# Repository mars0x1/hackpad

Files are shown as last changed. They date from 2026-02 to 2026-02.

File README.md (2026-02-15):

# Mars Hackpad 🚀
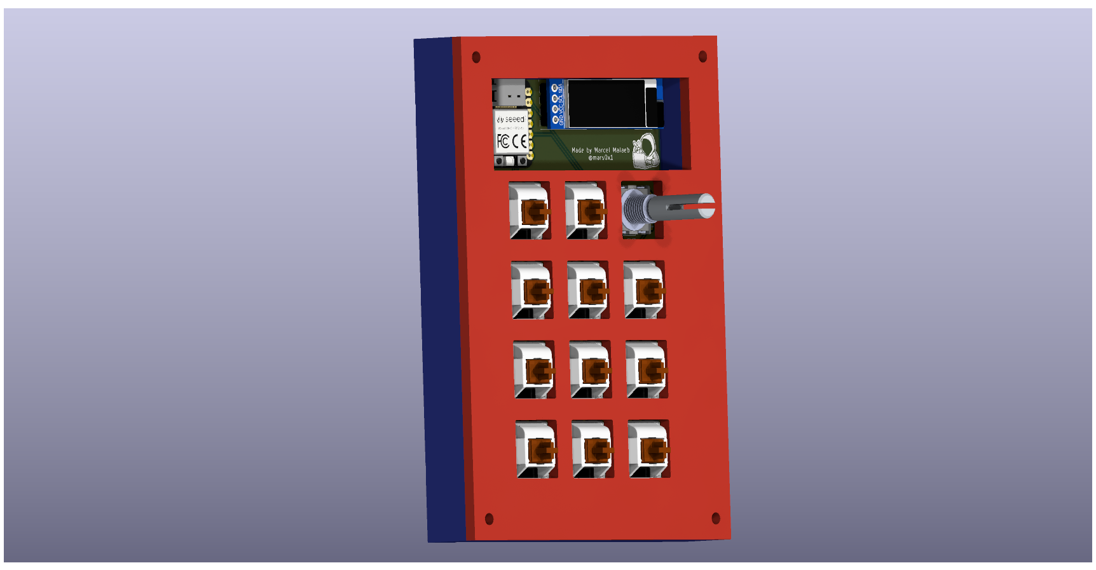
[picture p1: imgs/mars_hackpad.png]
mars_hackpad


Mars Hackpad is a 12-input productivity tool designed for seamless media control and custom shortcuts. It features an 11-key matrix and a rotary encoder, providing a tactical way to manage your workspace. It is powered by the **Seeed XIAO RP2040** and runs on **KMK firmware**.

## Features
* **128x64 OLED Display**: Provides real-time status updates via I2C (SDA: D4, SCL: D5).
* **EC11 Rotary Encoder**: Mapped to system volume control. Press the encoder to toggle **System Mute**.
* **11 Mechanical Keys**: Currently configured with macros for **Undo**, **Copy**, **Paste**, and a dedicated **Mic Mute** shortcut (FN + F5).
* **3D Printed Case**: A two-piece snap-fit design that holds the PCB and display at an ergonomic angle.

## CAD Model

* The case was designed in Fusion360 . 
* It consists of two printed parts: a **Top Case** with cutouts for the keys and screen, and a **Bottom Case** to protect the electronics.
* Everything is held together by M3 bolts.

## PCB
My PCB was designed in KiCad. It features a 4x3 matrix layout and custom silkscreen labeling.
* **Schematic**:
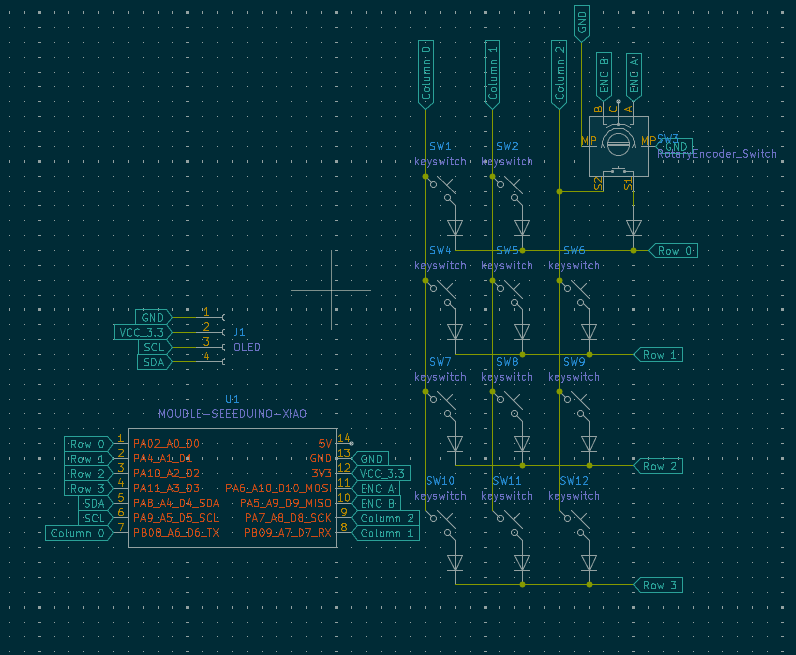
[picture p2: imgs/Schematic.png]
*  

* **PCB Layout**:
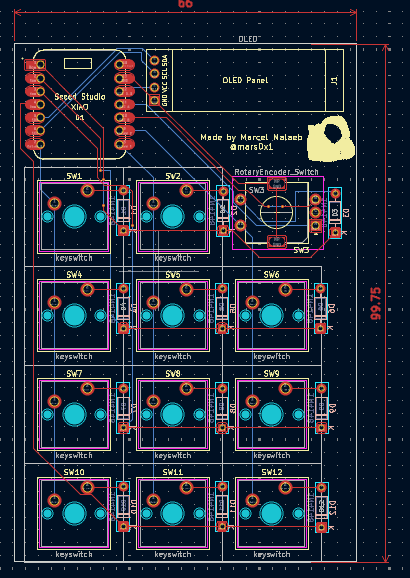
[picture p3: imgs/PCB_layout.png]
* 

* I used standard MX-style footprints for the keys and ensured the XIAO RP2040 sits centrally for easy USB-C access.
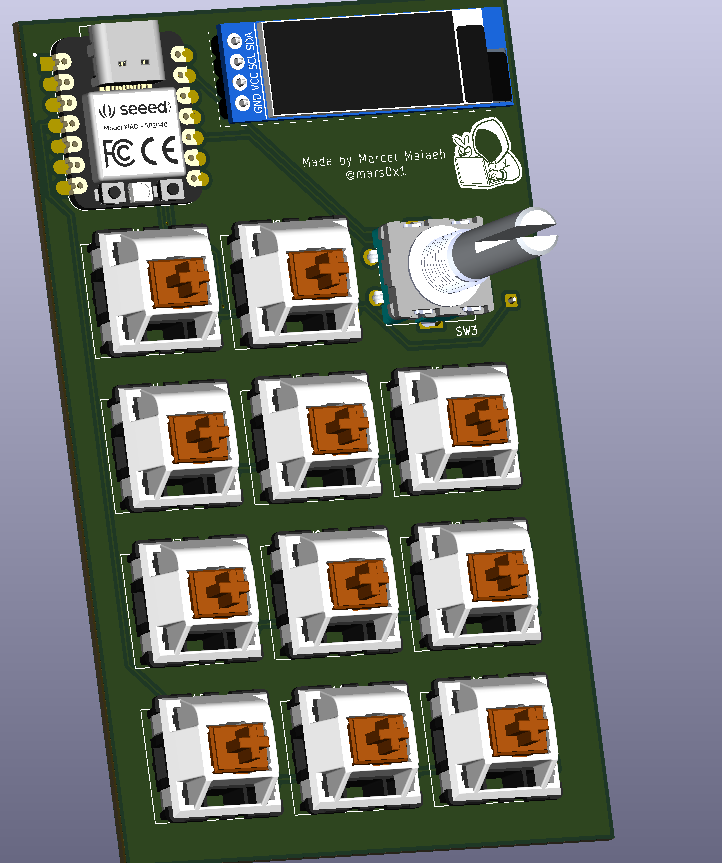
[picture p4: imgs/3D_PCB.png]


## Firmware Overview
This hackpad uses **KMK Firmware** (CircuitPython).
* **Matrix Setup**: Rows use pins **D0, D1, D2, D3** and Columns use **D6, D7, D9**.
* **Rotary Encoder**: Mapped to pins **D11** and **D10**.
* **Shortcuts**: The firmware is set up to handle common productivity commands without needing to touch the main keyboard.

## BOM (Bill of Materials)
Here is everything you need to build the Mars Hackpad:

| Item | Quantity | Description |
| :--- | :--- | :--- |
| **Seeed XIAO RP2040** | 1 | Main Microcontroller |
| **0.91 inch OLED display** | 1 | I2C Display |
| **EC11 Encoder** | 1 | Rotary Encoder with push-button |
| **MX Switches** | 11 | Your choice of mechanical switches |
| **1N4148 Diodes** | 12 | Switching Diodes for the matrix |
| **Case** | 2 parts | 3D Printed Top and Bottom shells |
| **M3 Bolts** | 4 | To secure the case halves |

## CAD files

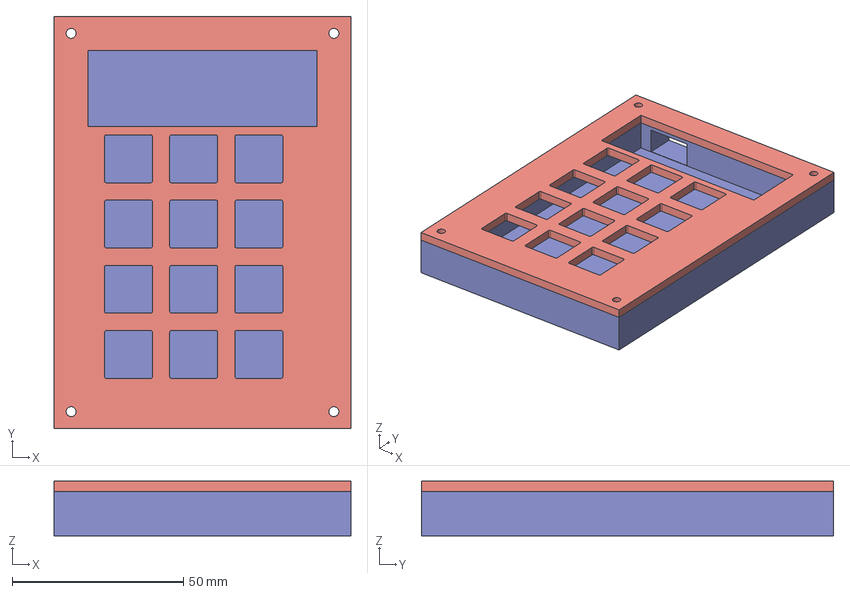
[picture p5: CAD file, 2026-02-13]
CAD/assembled_pad.step
86.8 x 120.5 x 16.0 mm

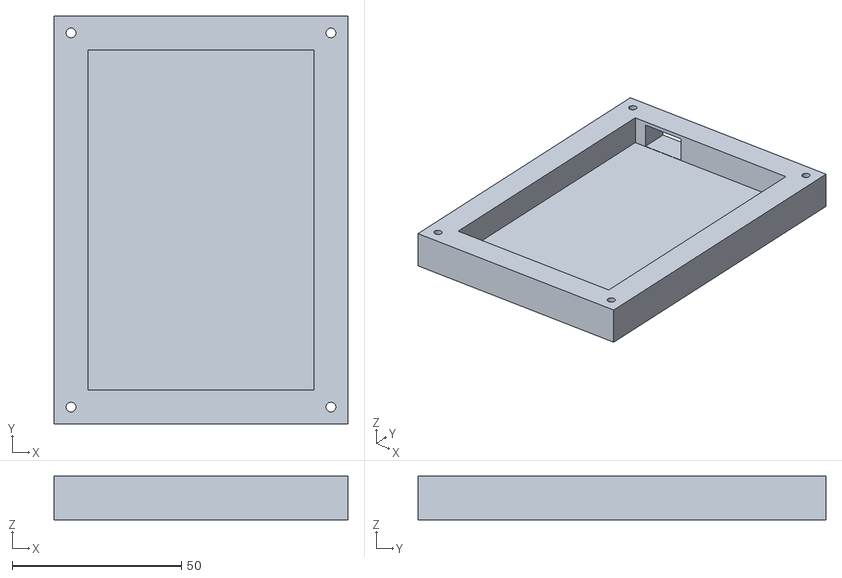
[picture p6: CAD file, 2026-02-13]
production/Bottom.stl
86.8 x 120.5 x 13.0

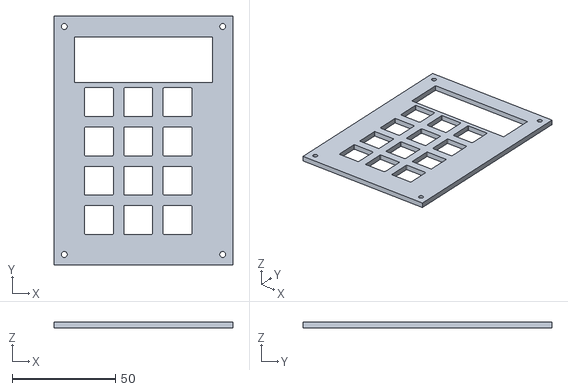
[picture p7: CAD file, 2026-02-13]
production/top.stl
86.8 x 120.5 x 3.00

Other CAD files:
CAD/case_only.step

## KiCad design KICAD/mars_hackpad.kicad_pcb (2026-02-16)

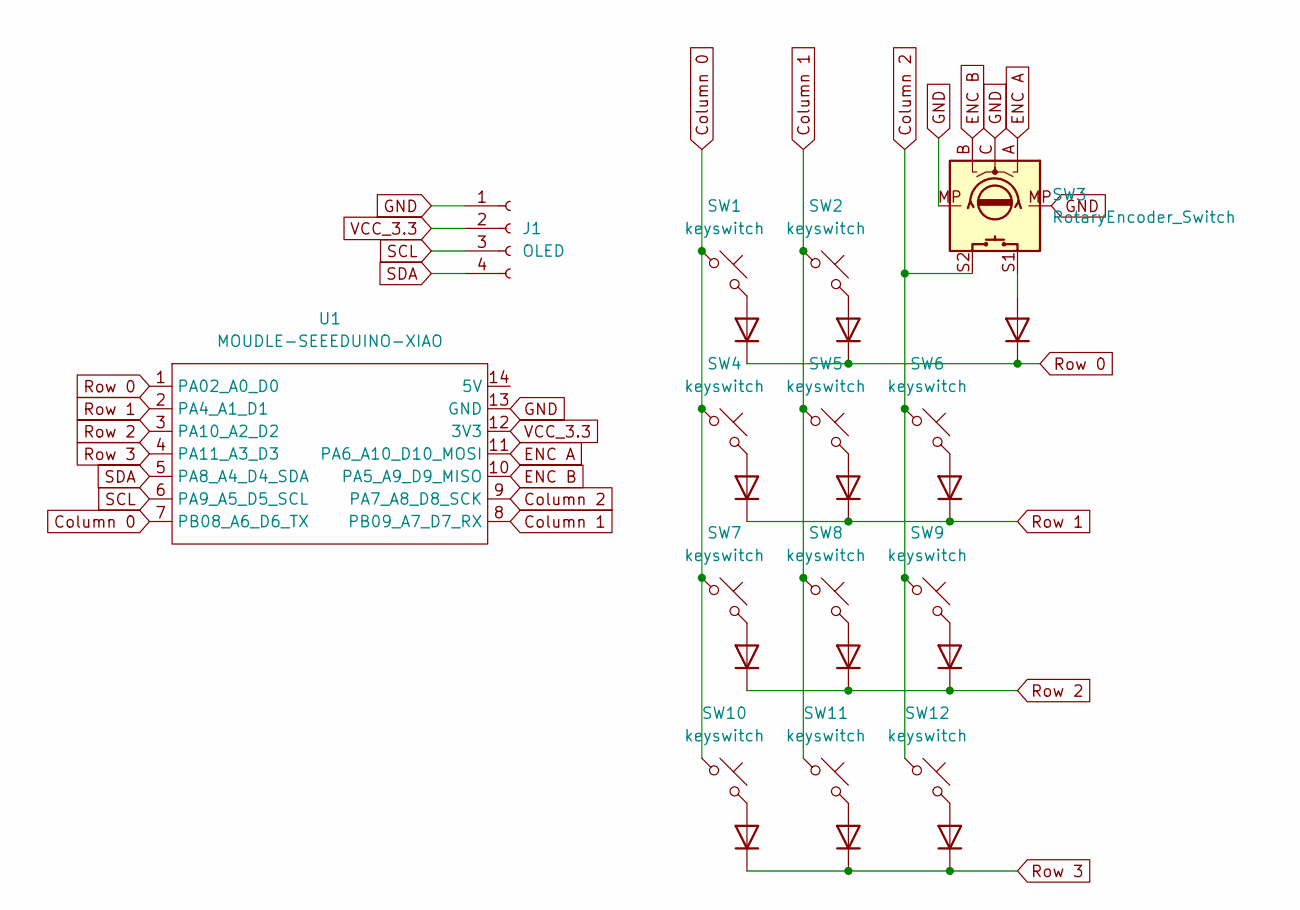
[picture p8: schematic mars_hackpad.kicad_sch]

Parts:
D1, D2, D3, D4, D5, D6, D7, D8, D9, D10, D11, D12: 1N4148; D_DO-35_SOD27_P7.62mm_Horizontal
J1: OLED; SSD1306-0.91-OLED-4pin-128x32
SW1, SW2, SW4, SW5, SW6, SW7, SW8, SW9, SW10, SW11, SW12: keyswitch; SW_Cherry_MX_1.00u_PCB1
SW3: RotaryEncoder_Switch; RotaryEncoder_Alps_EC11E-Switch_Vertical_H20mm
U1: MOUDLE-SEEEDUINO-XIAO; XIAO-Generic-Hybrid-14P-2.54-21X17.8MM

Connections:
Column 0: SW1.1, SW4.1, SW7.1, SW10.1, U1.7 (PB08_A6_D6_TX)
Column 1: SW2.1, SW5.1, SW8.1, SW11.1, U1.8 (PB09_A7_D7_RX)
Column 2: SW3.S2, SW6.1, SW9.1, SW12.1, U1.9 (PA7_A8_D8_SCK)
ENC A: SW3.A, U1.11 (PA6_A10_D10_MOSI)
ENC B: SW3.B, U1.10 (PA5_A9_D9_MISO)
GND: J1.1, SW3.C, SW3.MP, U1.13 (GND)
unnamed: D1.2 (A), SW1.2
unnamed: D2.2 (A), SW2.2
unnamed: D3.2 (A), SW3.S1
unnamed: D4.2 (A), SW4.2
unnamed: D5.2 (A), SW5.2
unnamed: D6.2 (A), SW6.2
unnamed: D7.2 (A), SW7.2
unnamed: D8.2 (A), SW8.2
unnamed: D9.2 (A), SW9.2
unnamed: D10.2 (A), SW10.2
unnamed: D11.2 (A), SW11.2
unnamed: D12.2 (A), SW12.2
Row 0: D1.1 (K), D2.1 (K), D3.1 (K), U1.1 (PA02_A0_D0)
Row 1: D4.1 (K), D5.1 (K), D6.1 (K), U1.2 (PA4_A1_D1)
Row 2: D7.1 (K), D8.1 (K), D9.1 (K), U1.3 (PA10_A2_D2)
Row 3: D10.1 (K), D11.1 (K), D12.1 (K), U1.4 (PA11_A3_D3)
SCL: J1.3, U1.6 (PA9_A5_D5_SCL)
SDA: J1.4, U1.5 (PA8_A4_D4_SDA)
VCC_3.3: J1.2, U1.12 (3V3)

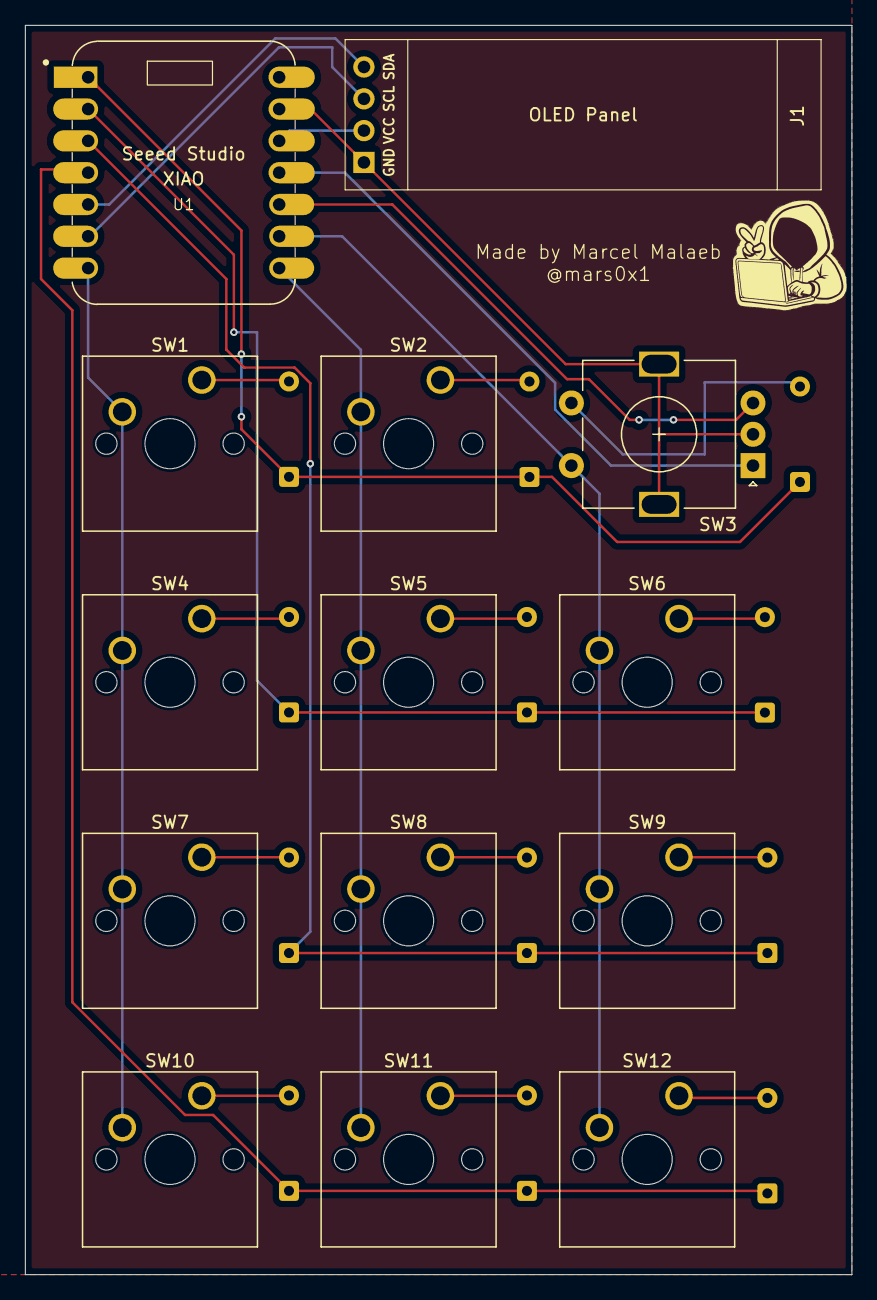
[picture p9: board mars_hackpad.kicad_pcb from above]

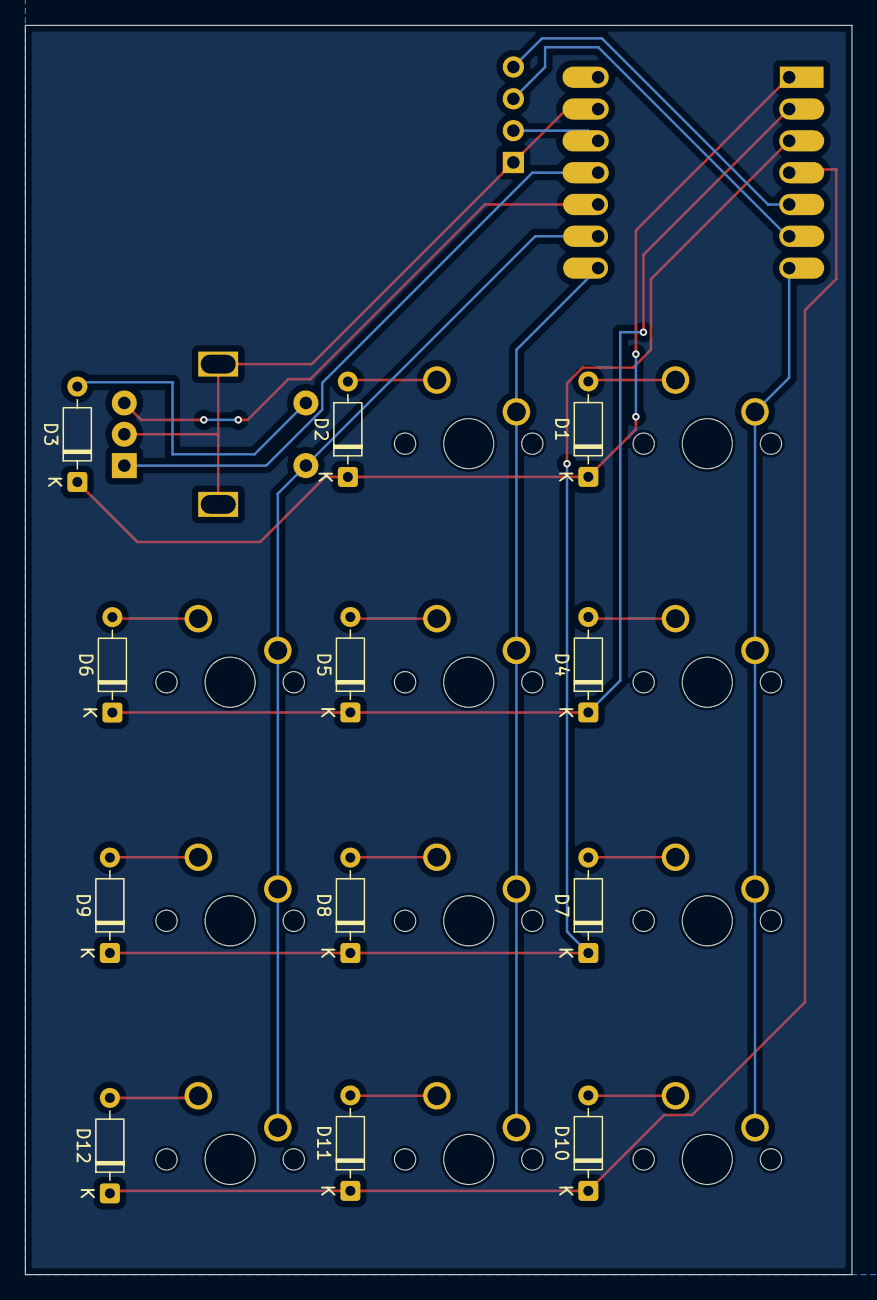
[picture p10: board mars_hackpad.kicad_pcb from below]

Board: 2 copper layers, 66.0 x 99.8 mm, 26 parts (12 on the bottom side), 25 nets.

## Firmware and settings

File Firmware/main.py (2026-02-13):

import board
from kmk.kmk_keyboard import KMKKeyboard
from kmk.keys import KC
from kmk.scanners import DiodeOrientation
from kmk.modules.encoder import EncoderHandler
from kmk.extensions.peg_oled_display import Oled, OledDisplayMode

keyboard = KMKKeyboard()

# --- 1. THE MATRIX CONFIGURATION ---
# Based on your XIAO pins
keyboard.row_pins = (board.D0, board.D1, board.D2, board.D3)
keyboard.col_pins = (board.D6, board.D7, board.D9)
keyboard.diode_orientation = DiodeOrientation.COL2ROW

# --- 2. THE ENCODER ROTATION (D10, D8) ---
encoder_handler = EncoderHandler()
keyboard.modules.append(encoder_handler)
encoder_handler.pins = ((board.D11, board.D10, None, False),)
encoder_handler.map = [((KC.VOLU, KC.VOLD),)] # Volume wheel

# --- 3. THE OLED DISPLAY ---
oled_ext = Oled(
    OledDisplayMode.TXT,
    oob_config={'scl': board.D5, 'sda': board.D4},
)
keyboard.extensions.append(oled_ext)

# --- 4. THE KEYMAP ---
# Row 1, Col 3 is your Encoder Click (Master Audio Mute)
# One of your other keys is now FN+F5 (Mic Mute)
keyboard.keymap = [
    [
        # ROW 1: Undo, Cut, SYSTEM AUDIO MUTE (Encoder Click)
        KC.LCTL(KC.Z), KC.LCTL(KC.X), KC.MUTE, 
        
        # ROW 2: Copy, Paste, MIC MUTE (FN + F5)
        KC.LCTL(KC.C), KC.LCTL(KC.V), KC.HYPR(KC.F5), 
        
        # ROW 3: Save, Play/Pause, Next Track
        KC.LCTL(KC.S), KC.MEDIA_PLAY_PAUSE, KC.MEDIA_NEXT_TRACK,
        
        # ROW 4: Alt+Tab, Desktop, Enter
        KC.LALT(KC.TAB), KC.LWIN(KC.D), KC.ENTER
    ]
]

if __name__ == '__main__':
    keyboard.go()

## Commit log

2026-02-13 Initial upload of pcb project folders
    [Bottom.stl, assembled_pad.step, mars_hackpad.kicad_pcb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]
2026-02-16 fixed the files
    [mars_hackpad.kicad_pcb, mars_hackpad.kicad_sch]
